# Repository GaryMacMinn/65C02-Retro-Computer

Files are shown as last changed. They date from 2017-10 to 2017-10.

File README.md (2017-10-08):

# 65C02-Retro-Computer
A retro computer system based on the 65C02 CPU in a modular format.

This is my first version of a retro 65C02 based comnputer. My original design for this project
was around a single board containing all of the parts (a single board computer!!). After a bit of an
initial draw up, I realised that there were a lot of unknown details to the design and if I needed to change anything it would mean producing an entire new PCB. After a little thought I decided to do a backplane design that allows sections and functionality to be plugged in as required. If I wanted to remove or change any
sections I could just redo that plug in card rather that everything. 

The system at present consists of:
* Backplane Board
* Power Supply and Reset Card
* CPU Card
* Memory Card (Combined Flash Memory and SRAM)
* Serial Card
* Parallel Card

The files included in the Schematic & PCB directory are the KiCAD schematic and PCB files as they stand
at the moment. These cards have been finalised, produced and tested. The others will be added as I build
and verify their designs.

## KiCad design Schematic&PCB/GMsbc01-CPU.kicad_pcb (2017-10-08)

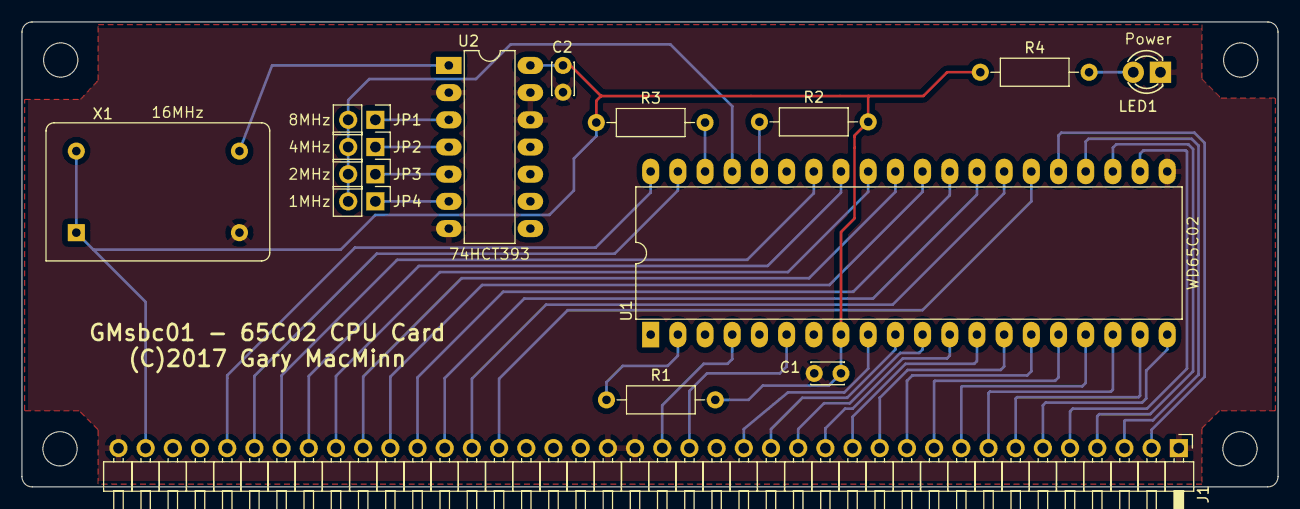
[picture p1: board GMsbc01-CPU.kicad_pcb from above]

Board: 2 copper layers, 117.3 x 43.4 mm, 19 parts (0 on the bottom side), 41 nets.

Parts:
1, 2, 3, 4: MountingHole_3.2mm_M3
C1, C2: 0.1uF; C_Disc_D3.0mm_W2.0mm_P2.50mm
J1: CONN_01X40; Pin_Header_Angled_1x40_Pitch2.54mm
JP1: 8MHz; Pin_Header_Straight_1x02_Pitch2.54mm
JP2: 4MHz; Pin_Header_Straight_1x02_Pitch2.54mm
JP3: 2MHz; Pin_Header_Straight_1x02_Pitch2.54mm
JP4: 1MHz; Pin_Header_Straight_1x02_Pitch2.54mm
LED1: Power; LED-3MM
R1, R2, R3: 3k3; R_Axial_DIN0207_L6.3mm_D2.5mm_P10.16mm_Horizontal
R4: 330R; R_Axial_DIN0207_L6.3mm_D2.5mm_P10.16mm_Horizontal
U1: WD65C02; DIP-40_W15.24mm_LongPads
U2: 74HCT393; DIP-14_W7.62mm_LongPads
X1: 16MHz; Oscillator_DIP-14

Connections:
+5v: C1.1, C2.1, J1.39, R1.2, R2.2, R3.2, R4.2, U1.8, U2.14, X1.1, X1.14
/IRQ: J1.20, U1.4
/NMI: J1.19, U1.6
/Reset: J1.36, U1.40
A0: J1.17, U1.9
A1: J1.16, U1.10
A2: J1.15, U1.11
A3: J1.14, U1.12
A4: J1.13, U1.13
A5: J1.12, U1.14
A6: J1.11, U1.15
A7: J1.10, U1.16
A8: J1.9, U1.17
A9: J1.8, U1.18
A10: J1.7, U1.19
A11: J1.6, U1.20
A12: J1.5, U1.22
A13: J1.4, U1.23
A14: J1.3, U1.24
A15: J1.2, U1.25
D0: J1.33, U1.33
D1: J1.32, U1.32
D2: J1.31, U1.31
D3: J1.30, U1.30
D4: J1.29, U1.29
D5: J1.28, U1.28
D6: J1.27, U1.27
D7: J1.26, U1.26
GND: C1.2, C2.2, J1.1, J1.21, J1.22, J1.40, LED1.1, U1.21, U2.2, U2.7, U2.12, U2.13, X1.7
unnamed: JP1.1, U2.3
unnamed: JP2.1, U2.4
unnamed: JP3.1, U2.5
unnamed: JP4.1, U2.6
unnamed: LED1.2, R4.1
unnamed: R1.1, U1.2
unnamed: R2.1, U1.36
unnamed: R3.1, U1.38
unnamed: U2.1, X1.8
Phi2: J1.35, U1.39
Phi2In: JP1.2, JP2.2, JP3.2, JP4.2, U1.37
R/-W: J1.34, U1.34

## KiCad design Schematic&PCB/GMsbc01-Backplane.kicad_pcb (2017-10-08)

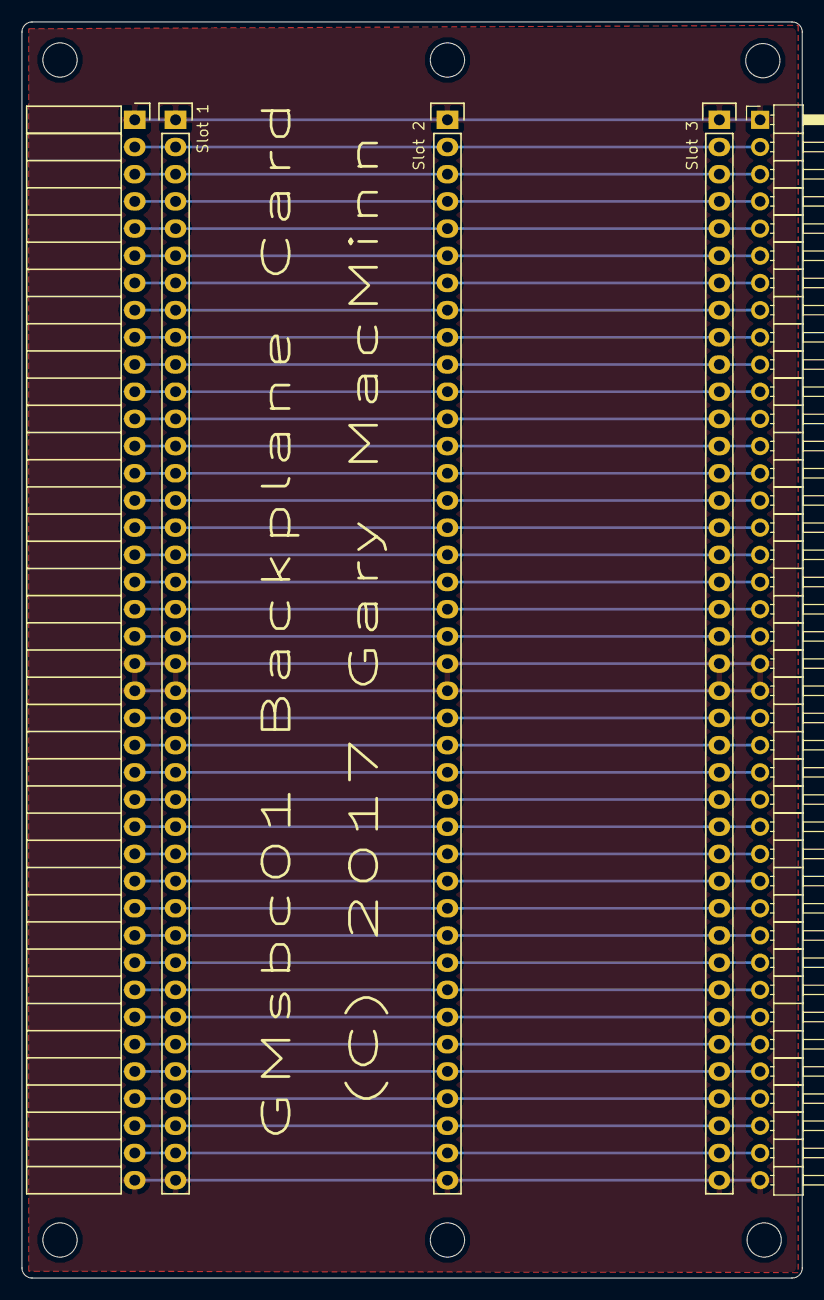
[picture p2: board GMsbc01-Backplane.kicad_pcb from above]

Board: 2 copper layers, 72.9 x 117.3 mm, 11 parts (0 on the bottom side), 37 nets.

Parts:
1, 2, 3, 7, 8, 9: MountingHole_3.2mm_M3
J1: Slot 4; Socket_Strip_Angled_1x40
J2: Slot 1; Socket_Strip_Straight_1x40
J3: Slot 2; Socket_Strip_Straight_1x40
J4: Slot 3; Socket_Strip_Straight_1x40
J5: Slot 5; Pin_Header_Angled_1x40_Pitch2.54mm

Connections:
+5v: J1.39, J2.39, J3.39, J4.39, J5.39
/IRQ: J1.20, J2.20, J3.20, J4.20, J5.20
/NMI: J1.19, J2.19, J3.19, J4.19, J5.19
/Reset: J1.36, J2.36, J3.36, J4.36, J5.36
A0: J1.17, J2.17, J3.17, J4.17, J5.17
A1: J1.16, J2.16, J3.16, J4.16, J5.16
A2: J1.15, J2.15, J3.15, J4.15, J5.15
A3: J1.14, J2.14, J3.14, J4.14, J5.14
A4: J1.13, J2.13, J3.13, J4.13, J5.13
A5: J1.12, J2.12, J3.12, J4.12, J5.12
A6: J1.11, J2.11, J3.11, J4.11, J5.11
A7: J1.10, J2.10, J3.10, J4.10, J5.10
A8: J1.9, J2.9, J3.9, J4.9, J5.9
A9: J1.8, J2.8, J3.8, J4.8, J5.8
A10: J1.7, J2.7, J3.7, J4.7, J5.7
A11: J1.6, J2.6, J3.6, J4.6, J5.6
A12: J1.5, J2.5, J3.5, J4.5, J5.5
A13: J1.4, J2.4, J3.4, J4.4, J5.4
A14: J1.3, J2.3, J3.3, J4.3, J5.3
A15: J1.2, J2.2, J3.2, J4.2, J5.2
D0: J1.33, J2.33, J3.33, J4.33, J5.33
D1: J1.32, J2.32, J3.32, J4.32, J5.32
D2: J1.31, J2.31, J3.31, J4.31, J5.31
D3: J1.30, J2.30, J3.30, J4.30, J5.30
D4: J1.29, J2.29, J3.29, J4.29, J5.29
D5: J1.28, J2.28, J3.28, J4.28, J5.28
D6: J1.27, J2.27, J3.27, J4.27, J5.27
D7: J1.26, J2.26, J3.26, J4.26, J5.26
GND: J1.1, J1.21, J1.22, J1.40, J2.1, J2.21, J2.22, J2.40, J3.1, J3.21, J3.22, J3.40, J4.1, J4.21, J4.22, J4.40, J5.1, J5.21, J5.22, J5.40
Phi2: J1.35, J2.35, J3.35, J4.35, J5.35
R/-W: J1.34, J2.34, J3.34, J4.34, J5.34
Spare1: J1.18, J2.18, J3.18, J4.18, J5.18
Spare2: J1.23, J2.23, J3.23, J4.23, J5.23
Spare3: J1.24, J2.24, J3.24, J4.24, J5.24
Spare4: J1.25, J2.25, J3.25, J4.25, J5.25
Spare5: J1.37, J2.37, J3.37, J4.37, J5.37
Spare6: J1.38, J2.38, J3.38, J4.38, J5.38

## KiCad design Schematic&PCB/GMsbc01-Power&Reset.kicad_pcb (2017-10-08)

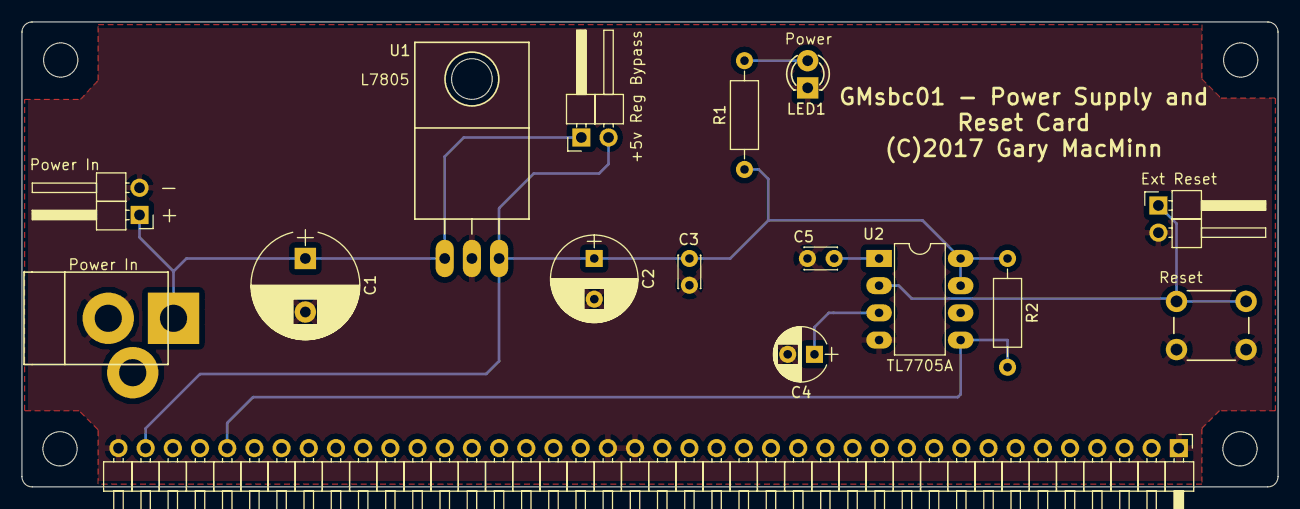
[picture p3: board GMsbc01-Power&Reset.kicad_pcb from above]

Board: 2 copper layers, 117.3 x 43.4 mm, 20 parts (0 on the bottom side), 8 nets.

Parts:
1, 2, 3, 4: MountingHole_3.2mm_M3
C1: 1000uF 25v; CP_Radial_D10.0mm_P5.00mm
C2: 470uF 16v; CP_Radial_D8.0mm_P3.80mm
C3, C5: 0.1uF; C_Disc_D3.0mm_W2.0mm_P2.50mm
C4: 100uF 16v; CP_Radial_D5.0mm_P2.50mm
J1: Slot 1; Pin_Header_Angled_1x40_Pitch2.54mm
J2: Power In; JACK_ALIM
J3: Power In; Pin_Header_Angled_1x02_Pitch2.54mm
J4: Ext Reset; Pin_Header_Angled_1x02_Pitch2.54mm
JP1: +5v Reg Bypass; Pin_Header_Angled_1x02_Pitch2.54mm
LED1: Power; LED-3MM
R1: 330R; R_Axial_DIN0207_L6.3mm_D2.5mm_P10.16mm_Horizontal
R2: 10k; R_Axial_DIN0207_L6.3mm_D2.5mm_P10.16mm_Horizontal
SW1: Reset; SW_PUSH_6mm
U1: L7805; TO-220_Neutral123_Horizontal_LargePads
U2: TL7705A; DIP-8_W7.62mm_LongPads

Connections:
+5v: C2.1, C3.1, J1.39, JP1.2, R1.1, R2.1, U1.3, U2.7, U2.8
/Reset: J1.36, R2.2, U2.5
GND: C1.2, C2.2, C3.2, C4.2, C5.2, J1.1, J1.21, J1.22, J1.40, J2.2, J3.2, J4.2, LED1.1, SW1.1, U1.2, U2.4
unnamed: C1.1, J2.1, J3.1, JP1.1, U1.1
unnamed: C4.1, U2.3
unnamed: C5.1, U2.1
unnamed: J4.1, SW1.2, U2.2
unnamed: LED1.2, R1.2

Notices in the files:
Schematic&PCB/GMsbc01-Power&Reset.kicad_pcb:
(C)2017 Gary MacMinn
